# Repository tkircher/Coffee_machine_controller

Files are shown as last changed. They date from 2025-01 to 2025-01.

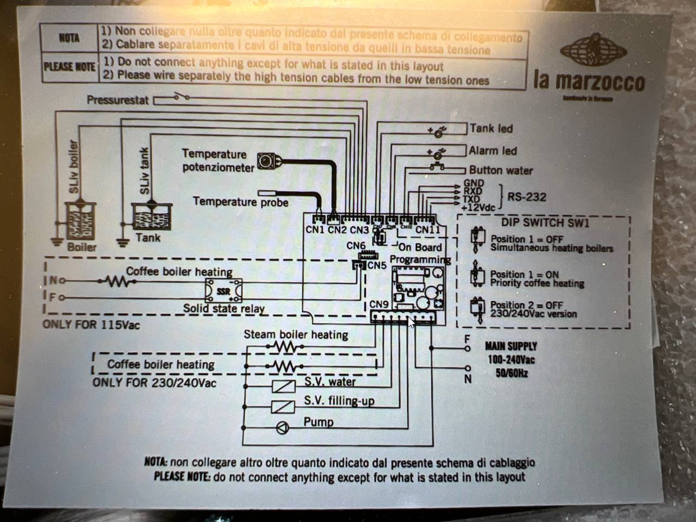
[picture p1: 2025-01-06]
Datasheets/La_Marzocco_control_board_diagram.jpg

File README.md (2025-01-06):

# Coffee_machine_controller
This is a control board for a Linea Mini coffee machine
control_board
control_board_assembled

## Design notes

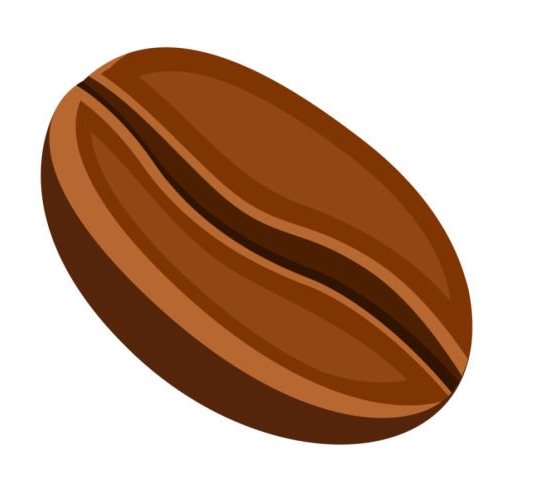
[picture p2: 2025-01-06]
Bean_graphics/coffee_bean_orig.jpg

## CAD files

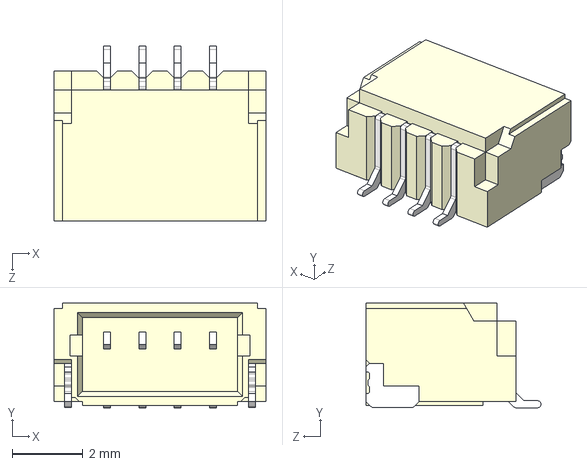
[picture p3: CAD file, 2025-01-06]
3D models/SM04B-SRSS.STEP
6.00 x 2.96 x 4.95 mm

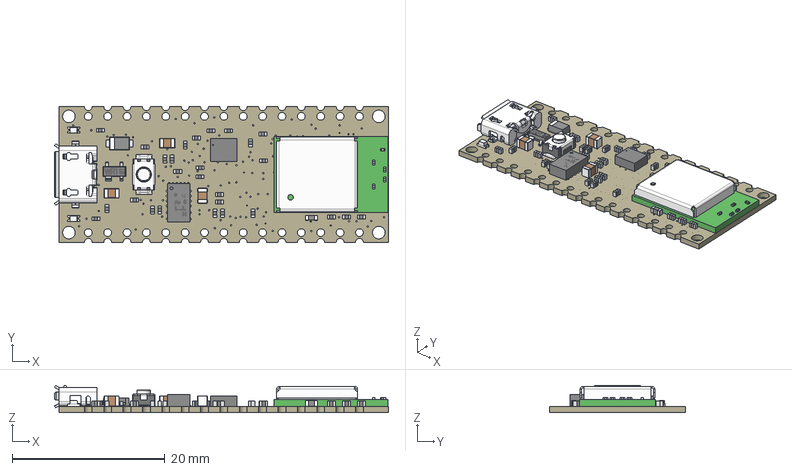
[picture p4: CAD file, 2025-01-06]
3D models/Nano33BLE.step
43.8 x 17.8 x 3.57 mm
Board (1)
LSM9DS1TR_LGA-24_3X3P5X1_STM v1
ZX62-AB-5PA (1)
IoT_HSMG-C190 LED v1 x 2
IoT_MPM3610 Step-Down Module v1
User Library-arduino_nano_reset core
User Library-arduino_nano_reset shell
RC0402FR-071KL RC0402N_YAG v1 x 27
BLM18EG101TN1D v1
C0805C472KDRACTU v1 x 3
PMEG6020AELRX v1
IoT_PRTR5V0U2X Protection Diode v1
NINA-B306-00B-00--3DModel-STEP-56544 v1

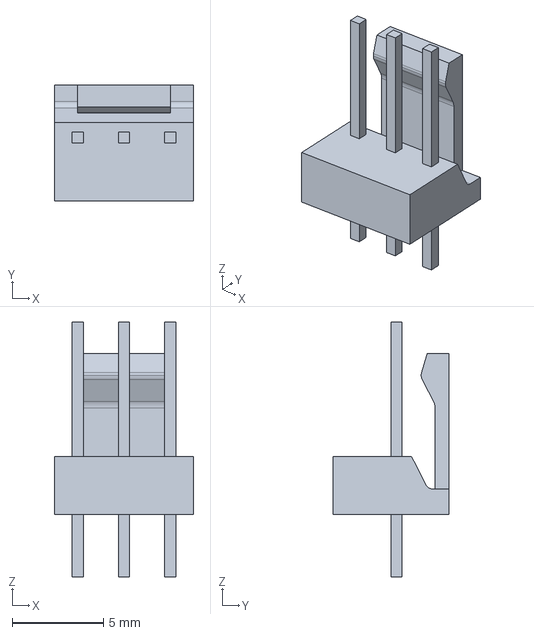
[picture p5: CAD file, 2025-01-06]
3D models/3-647050-3.step
7.62 x 6.35 x 14.0 mm

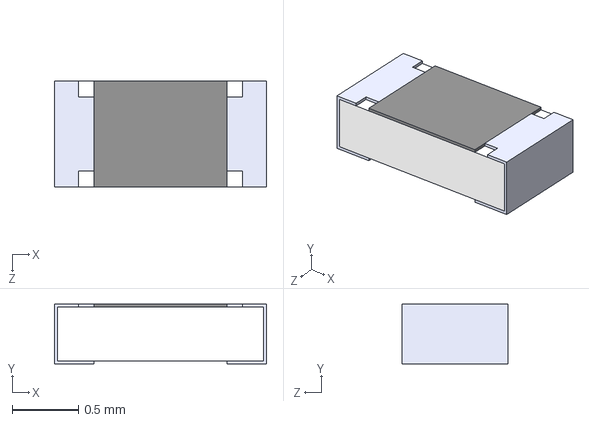
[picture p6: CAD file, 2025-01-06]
3D models/ERJPA3F1003V.step
1.60 x 0.45 x 0.8 mm

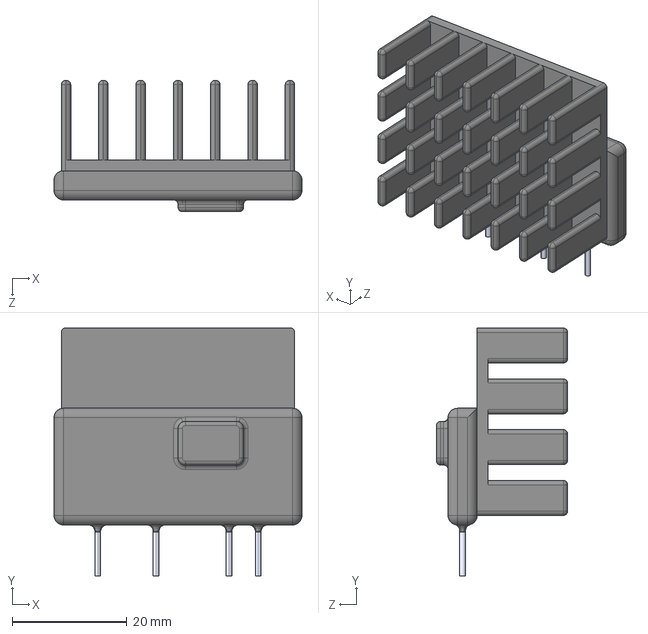
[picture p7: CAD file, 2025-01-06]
3D models/SPF240D25.step
43.2 x 43.2 x 22.9 mm

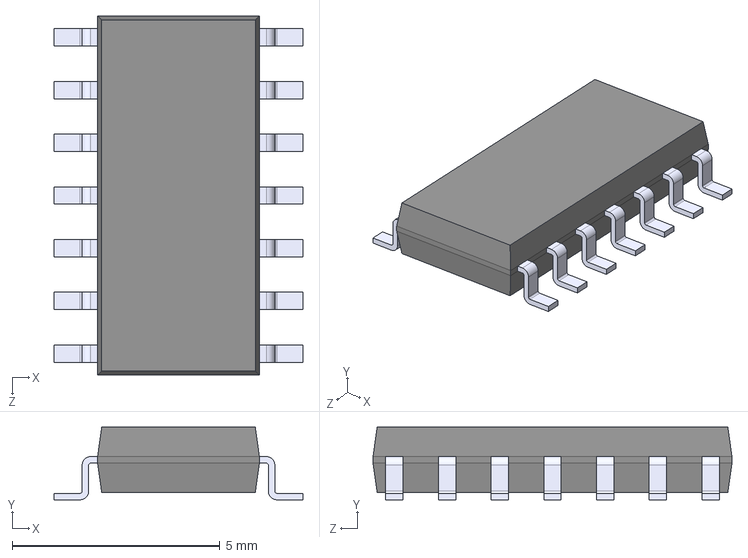
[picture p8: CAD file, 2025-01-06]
3D models/SN74LVC125AD.STEP
6.00 x 1.75 x 8.65 mm

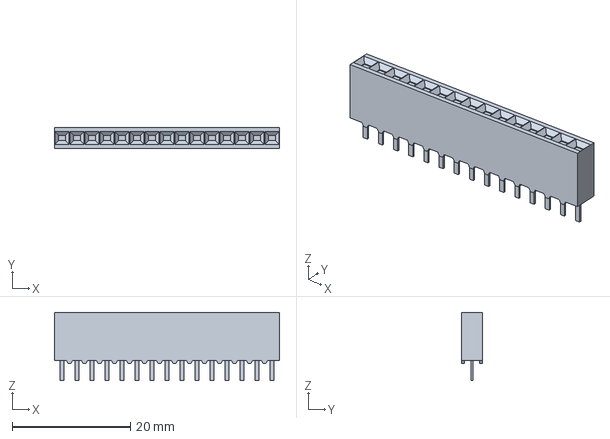
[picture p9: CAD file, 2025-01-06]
3D models/01x15_Arduino_socket.step
38.1 x 3.56 x 11.6 mm

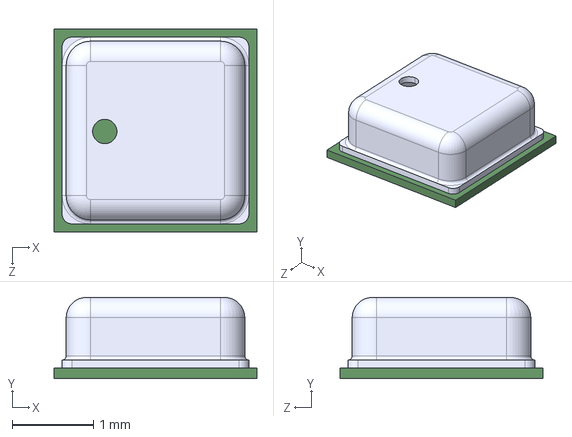
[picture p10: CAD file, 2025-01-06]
3D models/BME280.step
2.50 x 1.00 x 2.50 mm

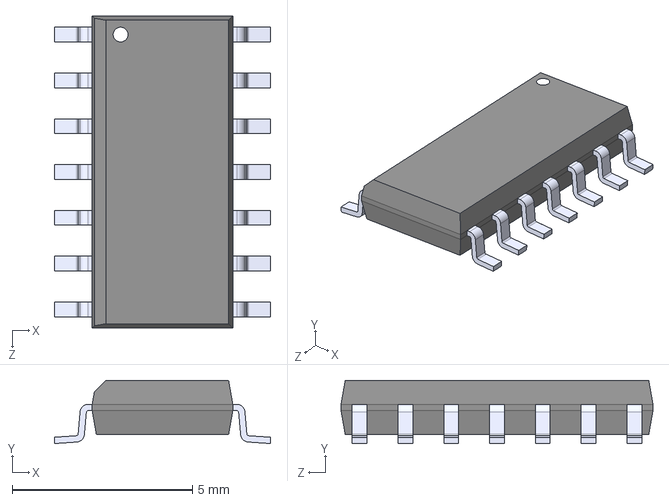
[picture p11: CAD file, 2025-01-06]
3D models/MCP3428-E_SL.step
6.00 x 1.75 x 8.65 mm

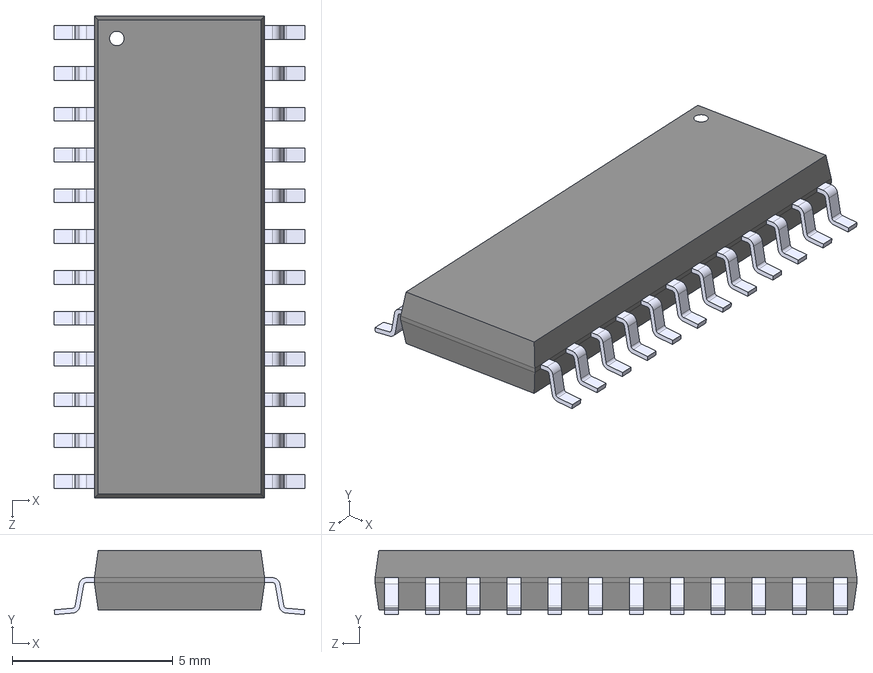
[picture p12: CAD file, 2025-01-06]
3D models/SN74LVC8T245NSR.STEP
7.80 x 2.00 x 15.0 mm

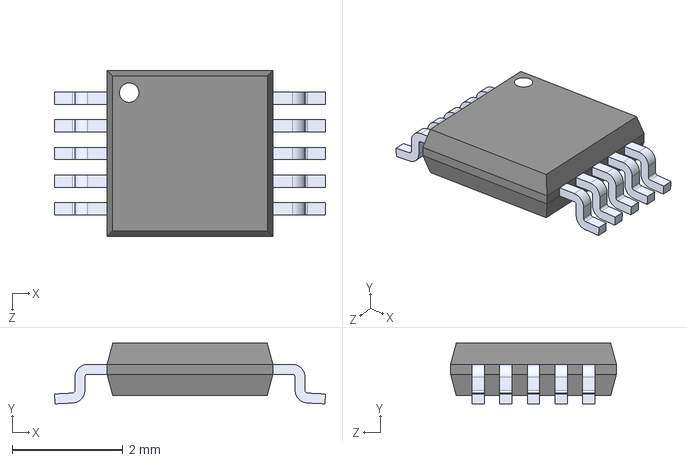
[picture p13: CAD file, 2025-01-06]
3D models/SOP50P490X110-10N.step
4.90 x 1.10 x 3.00 mm

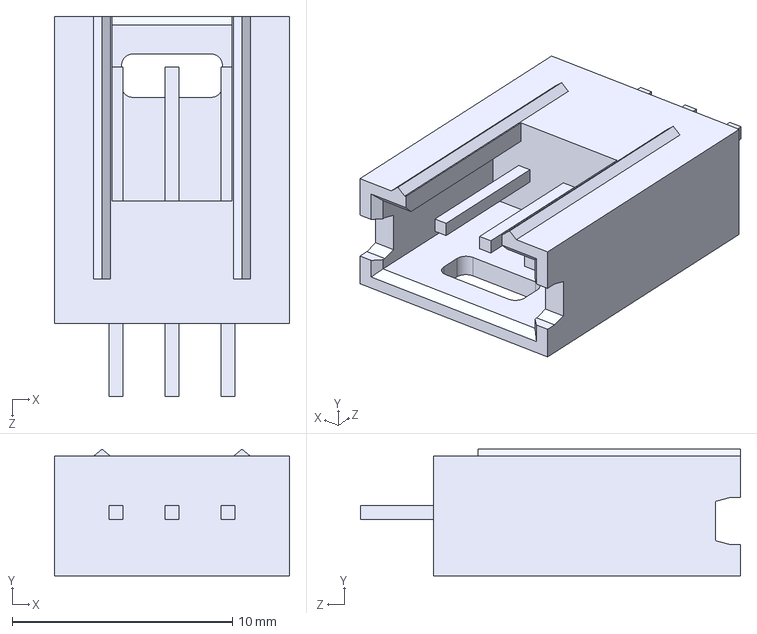
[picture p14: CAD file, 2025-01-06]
3D models/01x03_header.step
10.7 x 5.75 x 17.2 mm

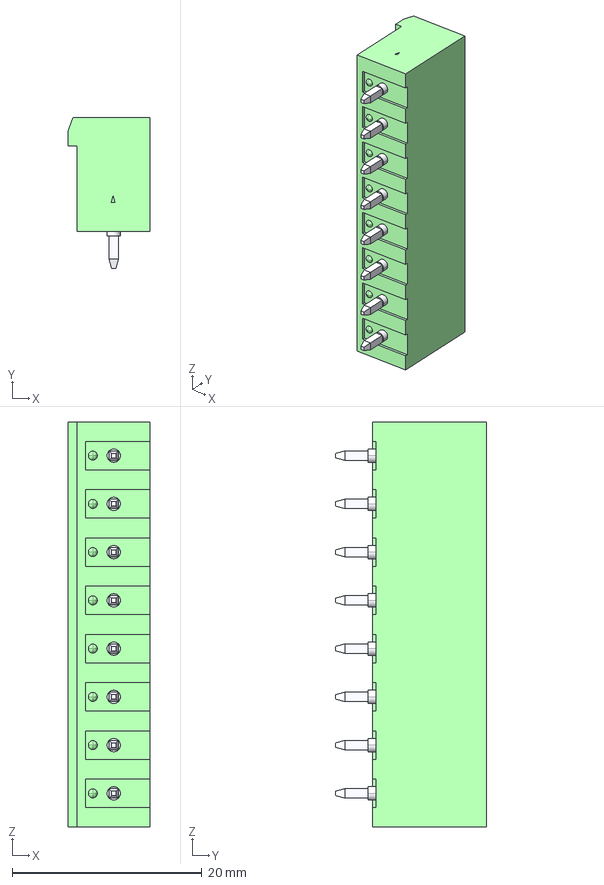
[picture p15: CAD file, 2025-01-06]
3D models/01x08_AC_socket.step
8.60 x 15.9 x 42.6 mm

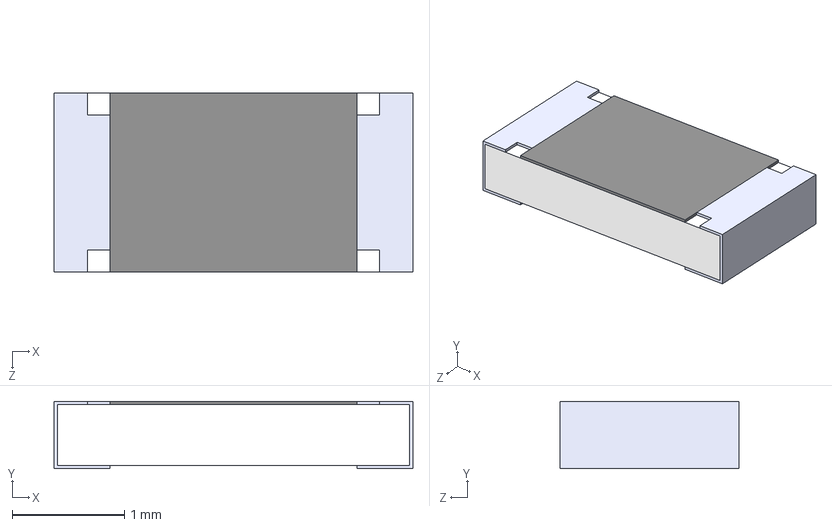
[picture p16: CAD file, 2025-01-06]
3D models/ERA8AEB105V.step
3.20 x 0.6 x 1.60 mm

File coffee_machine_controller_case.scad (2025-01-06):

// Basic case for coffee machine controller board
//
// Thomas Kircher <tkircher@gnu.org>, 2024

// PCB dimensions
board_h = 66;
board_w = 78;

// Mount hole positions
mount_x = 70;
mount_y = 58;

// Cover offsets
cover_h = board_h + 12 - 6;
cover_w = board_w + 12 - 6;
cover_t = 0.6 * 4 + 1.2;

cutout_h = mount_y + 2;
cutout_w = mount_x + 5;

// Middle section offsets
middle_h = board_h - 24;
middle_w = board_w - 20;

// Wall thickness
wall_t = 5 * 0.4;
wall_d1 = 6;
wall_d2 = wall_d1 + 2 * wall_t;

point_d = 3.2 + 2 * 0.4 * 6;

module bottom_outer_ring() {
  outer_d = 10;

  difference() {
    union() {
      // Base
      difference() {
        translate([-cover_w / 2, -cover_h / 2, 0])
          cube([cover_w, cover_h, cover_t]);

        translate([-cutout_w / 2, -cutout_h / 2 - 1 / 2, 1.2])
          cube([cutout_w - 1, cutout_h + 1, cover_t + 1]);
      }

      // Mount points
      for(i = [0 : 1])
      for(j = [0 : 1])
        mirror([i, 0, 0])
        mirror([0, j, 0]) {
        translate([mount_x / 2, mount_y / 2, 0]) {
          cylinder(d = point_d, h = cover_t, $fn = 120);

          translate([-point_d / 2, 0, 0])
            cube([point_d, point_d / 2, cover_t]);

          translate([0, -point_d / 2, 0])
            cube([point_d / 2 + 1, point_d, cover_t]);
        }
      }
    }

    // Mount holes and bottom chamfers
    for(i = [-1 : 2 : 1])
    for(j = [-1 : 2 : 1]) {
      translate([i * mount_x / 2, j * mount_y / 2, -0.1]) {
        cylinder(d = 3.2, h = cover_t + 1, $fn = 120);

        cylinder(d = 5.6, h = 1.2 + 0.1, $fn = 160);

        translate([0, 0, 1.2 + 0.1])
          cylinder(d1 = 5.6, d2 = 3.2, h = 1.8, $fn = 160);
      }
    }

    // Side wall outer fillets
    for(i = [0 : 1])
    for(j = [0 : 1]) {
      mirror([i, 0, 0])
      mirror([0, j, 0])
      translate([-cover_w / 2, -cover_h / 2, -0.1])
      difference() {
        translate([-1, -1, 0])
          cube([outer_d / 2 + 1, outer_d / 2 + 1, cover_t + 1]);

        translate([outer_d / 2, outer_d / 2, -0.1])
          cylinder(d = outer_d, h = cover_t + 2, $fn = outer_d * 24);
      }
    }
  }
}

module bottom_outer_walls(wall_h) {
  difference() {
    union() {
      // Side walls
      for(i = [0 : 1]) {
        mirror([i, 0, 0])
        translate([-cover_w / 2, -cover_h / 2, -wall_h + cover_t])
          cube([wall_t, cover_h, wall_h]);

        mirror([0, i, 0])
        translate([-cover_w / 2, -cover_h / 2, -wall_h + cover_t])
          cube([cover_w, wall_t, wall_h]);
      }

      // Side wall inner fillets
      for(i = [0 : 1])
      for(j = [0 : 1]) {
        mirror([i, 0, 0])
        mirror([0, j, 0]) {
        translate([-cover_w / 2 + wall_t, -cover_h / 2 + wall_t, -wall_h + cover_t])
          difference() {
            cube([wall_d1 / 2, wall_d1 / 2, wall_h]);

            translate([wall_d1 / 2, wall_d1 / 2, -0.1])
              cylinder(d = wall_d1, h = wall_h + 1, $fn = wall_d1 * 24);
          }
        }
      }
    }
    // Side wall outer fillets
    for(i = [0 : 1])
    for(j = [0 : 1]) {
      mirror([i, 0, 0])
      mirror([0, j, 0])
      translate([-cover_w / 2, -cover_h / 2, -0.1 - wall_h + cover_t])
      difference() {
        translate([-1, -1, 0])
          cube([wall_d2 / 2 + 1, wall_d2 / 2 + 1, wall_h + 1]);

        translate([wall_d2 / 2, wall_d2 / 2, -0.1])
          cylinder(d = wall_d2, h = wall_h + 2, $fn = wall_d2 * 24);
      }
    }

    // DC and I2C cutouts
    translate([cover_w / 2 - 45, cover_h / 2 - 10 / 2, cover_t - wall_h])
    difference() {
      cube([23, 10, 10]);

      // Bottom chamfers
      for(i = [0 : 1]) {
        translate([i * (23 + 2.5) - 2.5 / 2, 0, -2.5 / 2])
        rotate([0, 45, 0])
        translate([-5 / 2, 0, -5 / 2])
          cube([5, 5, 5]);
      }
    }

    // Top chamfers
    translate([cover_w / 2 - 45, cover_h / 2 - 10 / 2, cover_t - wall_h])
    for(i = [0 : 1]) {
      translate([i * (23 - 2.5) + 2.5 / 2, 1.5, wall_h + 2.5 / 2])
      rotate([0, 45, 0])
      translate([-5 / 2, 0, -5 / 2])
        cube([5, 5, 5]);
    }
  }
}

module top_outer_ring() {
  //offset = 2 * wall_t + 0.5;
  offset = 0;

  outer_d = 10 + offset;

  cover_h = board_h + 12 - 6 + offset;
  cover_w = board_w + 12 - 6 + offset;

  difference() {
    union() {
      // Base
      difference() {
        translate([-cover_w / 2, -cover_h / 2, 0])
          cube([cover_w, cover_h, cover_t]);

        translate([-cutout_w / 2, -cutout_h / 2 - 1 / 2, 1.2])
          cube([cutout_w - 1, cutout_h + 1, cover_t + 1]);
      }

      // Mount points
      for(i = [0 : 1])
      for(j = [0 : 1])
        mirror([i, 0, 0])
        mirror([0, j, 0]) {
        translate([mount_x / 2, mount_y / 2, 0]) {
          cylinder(d = point_d, h = cover_t, $fn = 120);

          translate([-point_d / 2, 0, 0])
            cube([point_d, point_d / 2, cover_t]);

          translate([0, -point_d / 2, 0])
            cube([point_d / 2 + 1, point_d, cover_t]);
        }
      }
    }

    // Mount holes and bottom chamfers
    for(i = [-1 : 2 : 1])
    for(j = [-1 : 2 : 1]) {
      translate([i * mount_x / 2, j * mount_y / 2, -0.1]) {
        cylinder(d = 3.2, h = cover_t + 1, $fn = 120);

        cylinder(d = 5.6, h = 0.8 + 0.1, $fn = 160);

        translate([0, 0, 0.8 + 0.1])
          cylinder(d1 = 5.6, d2 = 3.2, h = 1.8, $fn = 160);

      }
    }

    // Side wall outer fillets
    for(i = [0 : 1])
    for(j = [0 : 1]) {
      mirror([i, 0, 0])
      mirror([0, j, 0])
      translate([-cover_w / 2, -cover_h / 2, -0.1])
      difference() {
        translate([-1, -1, 0])
          cube([outer_d / 2 + 1, outer_d / 2 + 1, cover_t + 1]);

        translate([outer_d / 2, outer_d / 2, -0.1])
          cylinder(d = outer_d, h = cover_t + 2, $fn = outer_d * 24);
      }
    }
  }
}

module top_inset_walls(wall_h) {
  offset = -4.2;

  wall_d1 = 6 + offset;
  wall_d2 = wall_d1 + 2 * wall_t;

  cover_h = board_h + 12 - 6 + offset;
  cover_w = board_w + 12 - 6 + offset;

  difference() {
    union() {
      // Side walls
      for(i = [0 : 1]) {
        mirror([i, 0, 0])
        translate([-cover_w / 2, -cover_h / 2, -wall_h + cover_t])
          cube([wall_t, cover_h, wall_h]);

        mirror([0, i, 0])
        translate([-cover_w / 2, -cover_h / 2, -wall_h + cover_t])
          cube([cover_w, wall_t, wall_h]);
      }

      // Side wall inner fillets
      for(i = [0 : 1])
      for(j = [0 : 1]) {
        mirror([i, 0, 0])
        mirror([0, j, 0]) {
        translate([-cover_w / 2 + wall_t, -cover_h / 2 + wall_t, -wall_h + cover_t])
          difference() {
            cube([wall_d1 / 2, wall_d1 / 2, wall_h]);

            translate([wall_d1 / 2, wall_d1 / 2, -0.1])
              cylinder(d = wall_d1, h = wall_h + 1, $fn = wall_d1 * 24);
          }
        }
      }
    }

    // Side wall outer fillets
    for(i = [0 : 1])
    for(j = [0 : 1]) {
      mirror([i, 0, 0])
      mirror([0, j, 0])
      translate([-cover_w / 2, -cover_h / 2, -0.1 - wall_h + cover_t])
      difference() {
        translate([-1, -1, 0])
          cube([wall_d2 / 2 + 1, wall_d2 / 2 + 1, wall_h + 1]);

        translate([wall_d2 / 2, wall_d2 / 2, -0.1])
          cylinder(d = wall_d2, h = wall_h + 2, $fn = wall_d2 * 24);
      }
    }
  }
}

module top_outer_walls(wall_h) {
  wall_t = 2.0 + 0.4;
  offset = 0;

  wall_d1 = 6 + offset;
  wall_d2 = wall_d1 + 2 * 2.0;

  cover_h = board_h + 12 - 6 + offset;
  cover_w = board_w + 12 - 6 + offset;

  difference() {
    union() {
      // Side walls
      for(i = [0 : 1]) {
        mirror([i, 0, 0])
        translate([-cover_w / 2, -cover_h / 2, -wall_h + cover_t])
          cube([wall_t, cover_h, wall_h]);

        mirror([0, i, 0])
        translate([-cover_w / 2, -cover_h / 2, -wall_h + cover_t])
          cube([cover_w, wall_t, wall_h]);
      }

      // Side wall inner fillets
      for(i = [0 : 1])
      for(j = [0 : 1]) {
        mirror([i, 0, 0])
        mirror([0, j, 0]) {
        translate([-cover_w / 2 + wall_t, -cover_h / 2 + wall_t, -wall_h + cover_t])
          difference() {
            cube([wall_d1 / 2, wall_d1 / 2, wall_h]);

            translate([wall_d1 / 2, wall_d1 / 2, -0.2])
              cylinder(d = wall_d1, h = wall_h + 0.4, $fn = wall_d1 * 24);
          }
        }
      }

      translate([0, 0, cover_t - wall_h + 19 + 2 - 7])
        top_inset_walls(19 + 2);
    }

    // Side wall outer fillets
    for(i = [0 : 1])
    for(j = [0 : 1]) {
      mirror([i, 0, 0])
      mirror([0, j, 0])
      translate([-cover_w / 2, -cover_h / 2, -0.1 - wall_h + cover_t])
      difference() {
        translate([-1, -1, 0])
          cube([wall_d2 / 2 + 1, wall_d2 / 2 + 1, wall_h + 1]);

        translate([wall_d2 / 2, wall_d2 / 2, -0.1])
          cylinder(d = wall_d2, h = wall_h + 2, $fn = wall_d2 * 24);
      }
    }
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

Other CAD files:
3D models/01x06_header.step
3D models/01x04_header.step
3D models/aq1208.step
3D models/RAC05-05SK.step
3D models/01x02_socket.step
3D models/103906-6.step
3D models/AQG22105.step
3D models/MCP23008-E_SO.STEP

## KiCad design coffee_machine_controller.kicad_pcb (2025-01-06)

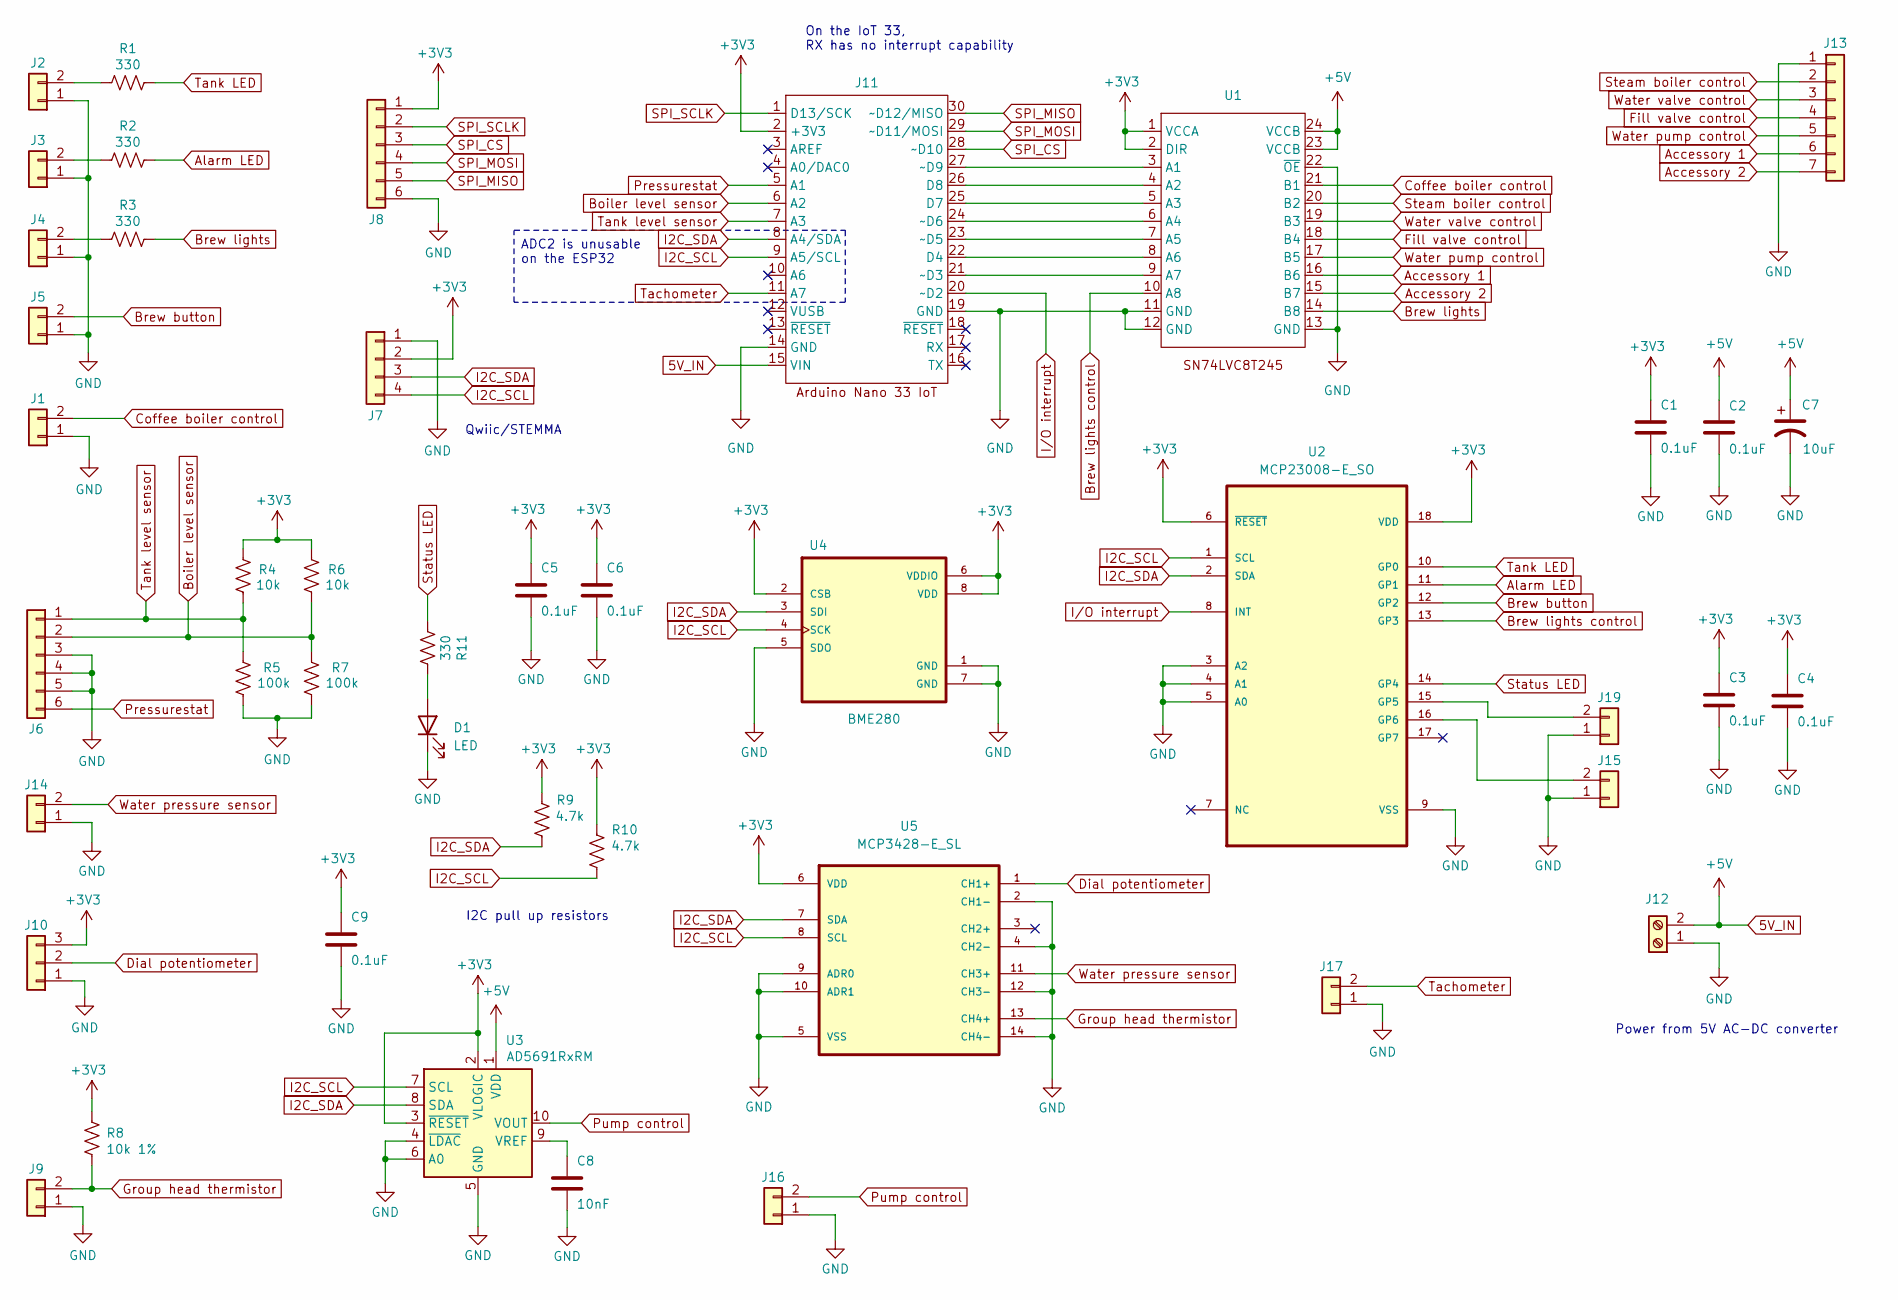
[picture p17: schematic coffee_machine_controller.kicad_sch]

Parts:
C1, C2, C3, C4, C5, C6, C9: 0.1uF; C_0805_2012Metric
C7: 10uF; CP_EIA-3216-18_Kemet-A
C8: 10nF; C_0805_2012Metric
D1: LED; LED_0805_2012Metric
J1, J2, J3, J4, J5, J9, J14, J15, J16, J17, J19: Conn_01x02; PinHeader_1x02_P2.54mm_Vertical
J6: Conn_01x06; PinHeader_1x06_P2.54mm_Vertical
J7: Conn_01x04; JST_SH_SM04B-SRSS-TB_1x04-1MP_P1.00mm_Horizontal
J8: Conn_01x06; PinHeader_1x06_P2.54mm_Vertical_DNP
J10: Conn_01x03; PinHeader_1x03_P2.54mm_Vertical
J11: Arduino_Nano_33_IoT_SMD
J12: Screw_Terminal_01x02; Terminal_block_01x02
J13: Conn_01x07; PinSocket_1x07_P2.54mm_Vertical
R1, R2, R3, R11: 330; R_0805_2012Metric
R4, R6: 10k; R_0805_2012Metric
R5, R7: 100k; R_0805_2012Metric
R8: 10k 1%; R_0805_2012Metric
R9, R10: 4.7k; R_0805_2012Metric
U1: SOP127P780X200-24N
U2: MCP23008-E_SO; SOIC127P1030X265-18N
U3: AD5691RxRM; MSOP-10_3x3mm_P0.5mm
U4: BME280; PSON65P250X250X100-8N
U5: MCP3428-E_SL; SOIC127P600X175-14N

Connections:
5V_IN: C2.1, C7.1, J11.15 (VIN), J12.2, U1.23 (VCCB), U1.24 (VCCB), U3.1 (VDD)
+3V3: C1.1, C3.1, C4.1, C5.1, C6.1, C9.1, J7.2, J8.1, J10.3, J11.2 (+3V3), R4.2, R6.2, R8.2, R9.2, R10.2, U1.1 (VCCA), U1.2 (DIR), U2.6 (~RESET), U2.18 (VDD), U3.2 (VLOGIC), U3.3 (~RESET), U4.2 (CSB), U4.6 (VDDIO), U4.8 (VDD), U5.6 (VDD)
Accessory 1: J13.6, U1.16 (B6)
Accessory 2: J13.7, U1.15 (B7)
Alarm LED: R2.2, U2.11 (GP1)
Boiler level sensor: J6.2, J11.6 (A2), R6.1, R7.2
Brew button: J5.2, U2.12 (GP2)
Brew lights: R3.2, U1.14 (B8)
Brew lights control: U1.10 (A8), U2.13 (GP3)
Coffee boiler control: J1.2, U1.21 (B1)
Dial potentiometer: J10.2, U5.1 (CH1+)
Fill valve control: J13.4, U1.18 (B4)
GND: C1.2, C2.2, C3.2, C4.2, C5.2, C6.2, C7.2, C8.2, C9.2, D1.1 (K), J1.1, J2.1, J3.1, J4.1, J5.1, J6.3, J6.4, J6.5, J7.1, J8.6, J9.1, J10.1, J11.14 (GND), J11.19 (GND), J12.1, J13.1, J14.1, J15.1, J16.1, J17.1, J19.1, R5.1, R7.1, U1.11 (GND), U1.12 (GND), U1.13 (GND), U1.22 (~OE), U2.3 (A2), U2.4 (A1), U2.5 (A0), U2.9 (VSS), U3.4 (~LDAC), U3.5 (GND), U3.6 (A0), U4.1 (GND), U4.5 (SDO), U4.7 (GND), U5.2 (CH1-), U5.4 (CH2-), U5.5 (VSS), U5.9 (ADR0), U5.10 (ADR1), U5.12 (CH3-), U5.14 (CH4-)
Group head thermistor: J9.2, R8.1, U5.13 (CH4+)
I2C_SCL: J7.4, J11.9 (A5/SCL), R10.1, U2.1 (SCL), U3.7 (SCL), U4.4 (SCK), U5.8 (SCL)
I2C_SDA: J7.3, J11.8 (A4/SDA), R9.1, U2.2 (SDA), U3.8 (SDA), U4.3 (SDI), U5.7 (SDA)
I/O interrupt: J11.20 (~D2), U2.8 (INT)
unnamed: D1.2 (A), R11.2
unnamed: J2.2, R1.1
unnamed: J3.2, R2.1
unnamed: J4.2, R3.1
unnamed: J11.22 (D4), U1.8 (A6)
unnamed: J11.25 (D7), U1.5 (A3)
unnamed: J11.26 (D8), U1.4 (A2)
unnamed: J11.21 (~D3), U1.9 (A7)
unnamed: J11.23 (~D5), U1.7 (A5)
unnamed: J11.24 (~D6), U1.6 (A4)
unnamed: J11.27 (~D9), U1.3 (A1)
unnamed: J15.2, U2.16 (GP6)
unnamed: J19.2, U2.15 (GP5)
unnamed: C8.1, U3.9 (VREF)
Pressurestat: J6.6, J11.5 (A1)
Pump control: J16.2, U3.10 (VOUT)
SPI_CS: J8.3, J11.28 (~D10)
SPI_MISO: J8.5, J11.30 (~D12/MISO)
SPI_MOSI: J8.4, J11.29 (~D11/MOSI)
SPI_SCLK: J8.2, J11.1 (D13/SCK)
Status LED: R11.1, U2.14 (GP4)
Steam boiler control: J13.2, U1.20 (B2)
Tachometer: J11.11 (A7), J17.2
Tank LED: R1.2, U2.10 (GP0)
Tank level sensor: J6.1, J11.7 (A3), R4.1, R5.2
Water pressure sensor: J14.2, U5.11 (CH3+)
Water pump control: J13.5, U1.17 (B5)
Water valve control: J13.3, U1.19 (B3)

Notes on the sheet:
Qwiic/STEMMA
I2C pull up resistors
On the IoT 33, RX has no interrupt capability
Power from 5V AC-DC converter
ADC2 is unusable on the ESP32

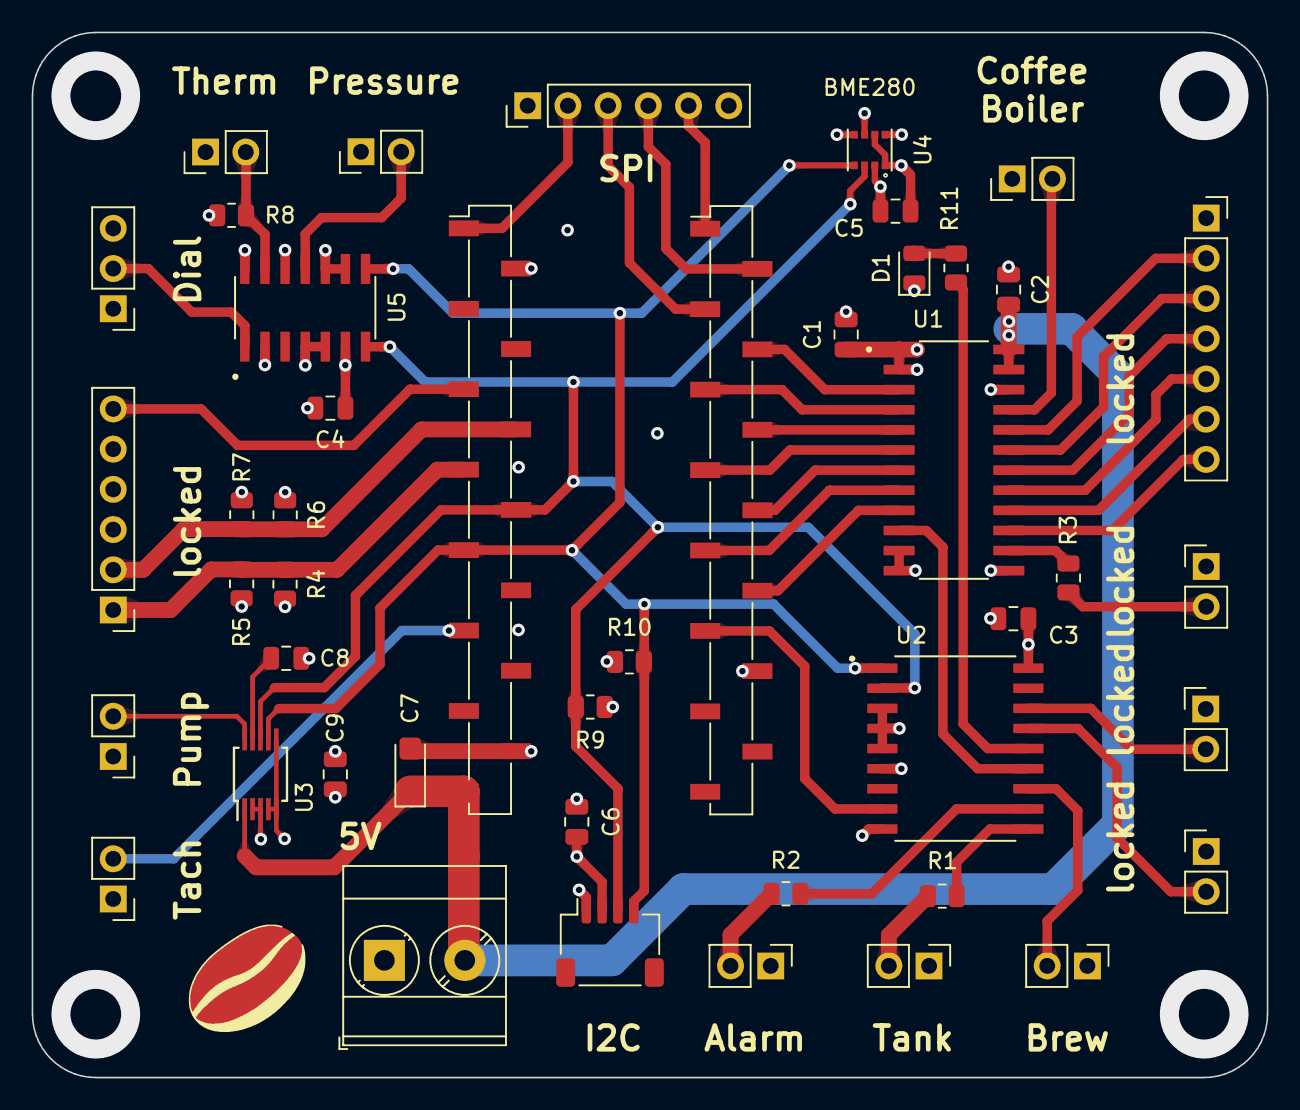
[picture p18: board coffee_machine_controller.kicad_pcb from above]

Board: 4 copper layers, 78.0 x 66.0 mm, 44 parts (0 on the bottom side), 45 nets.

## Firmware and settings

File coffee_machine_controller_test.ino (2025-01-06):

#include <Wire.h>
#include <Adafruit_MCP23X08.h>
#include <Adafruit_BME280.h>
#include <Adafruit_AD569x.h>
#include <MCP342x.h>

// Whether we're building for ESP32 or not
#undef ESP32

// Pin    Arduino pin     ESP32 GPIO     Function
// ---    -----------     ----------     --------
// D0      0              44             -
// D1      1              43             -
// D2      2               5             I/O interrupt
// D3      3               6             Accessory 2
// D4      4               7             Accessory 1
// D5      5               8             Water pump control
// D6      6               9             Fill valve control
// D7      7              10             Water valve control
// D8      8              17             Steam boiler control
// D9      9              18             Coffee boiler control
// D10    10              21             SPI_CS
// D11    11              38             SPI_MOSI
// D12    12              47             SPI_MISO
// D13    13              48             SPI_SCLK
// LED_R  14              46             -
// LED_G  15               0             -
// LED_B  16              45             -
// A0     17               1             -
// A1     18               2             Pressurestat
// A2     19               3             Boiler level sensor
// A3     20               4             Tank level sensor
// A4     21              11             I2C_SDA
// A5     22              12             I2C_SCL
// A6     23              13             -
// A7     24              14             Gear pump tachometer


#ifdef ESP32 // We are using GPIO numbering

#define IO_INTERRUPT            5
#define WATER_PUMP              8
#define ACCESSORY_1             7
#define ACCESSORY_2             6
#define WATER_VALVE             10
#define FILL_VALVE              9
#define STEAM_BOILER            17
#define COFFEE_BOILER           18

#define LED_R                   46
#define LED_G                   0
#define LED_B                   45

#define PRESSURESTAT            2
#define BOILER_AUTOFILL_PROBE   3
#define RESERVOIR_LEVEL_PROBE   4
#define TACHOMETER              14

#else // Arduino IoT 33

#define IO_INTERRUPT            2
#define WATER_PUMP              5
#define ACCESSORY_1             4
#define ACCESSORY_2             3
#define WATER_VALVE             7
#define FILL_VALVE              6
#define STEAM_BOILER            8
#define COFFEE_BOILER           9

#define PRESSURESTAT            A1
#define BOILER_AUTOFILL_PROBE   A2
#define RESERVOIR_LEVEL_PROBE   A3
#define TACHOMETER              A7

#endif // ESP32 or IoT 33

// These are the port numbers for the I/O expander
#define TANK_LED                0
#define ALARM_LED               1
#define BREW_BUTTON             2
#define BREW_LIGHTS             3
#define STATUS_LED              4
#define IO_1                    5
#define IO_2                    6
// GP7 not used

// These are the channel numbers for the ADC
#define DIAL_POTENTIOMETER      1
// Channel 2 is shorted to ground
#define PRESSURE_SENSOR         3
#define THERMISTOR              4

Adafruit_MCP23X08 mcp;
Adafruit_BME280 bme;
Adafruit_AD569x ad5693; // 12-bit DAC
MCP342x adc = MCP342x(0x68); // MCP3424 address is 0x6e

int i;
int timeout = 1000000; // 1 second timeout

float boiler_probe;
float reservoir_probe;
int pressurestat;
float potentiometer;
float pressure;
float thermistor;
float bme_temperature;
float bme_pressure;
float bme_humidity;

int DAC_value = 0;
bool button_flag = false;

#ifdef ESP32

void IRAM_ATTR isr() {
  button_flag = true;
}

const uint8_t HSVlights[61] = 
{0, 4, 8, 13, 17, 21, 25, 30, 34, 38, 42, 47, 51, 55, 59, 64, 68, 72, 76,
81, 85, 89, 93, 98, 102, 106, 110, 115, 119, 123, 127, 132, 136, 140, 144,
149, 153, 157, 161, 166, 170, 174, 178, 183, 187, 191, 195, 200, 204, 208,
212, 217, 221, 225, 229, 234, 238, 242, 246, 251, 255};

// the real HSV rainbow
void trueHSV(int angle)
{
  byte red, green, blue;

  if (angle<60) {red = 255; green = HSVlights[angle]; blue = 0;} else
  if (angle<120) {red = HSVlights[120-angle]; green = 255; blue = 0;} else 
  if (angle<180) {red = 0, green = 255; blue = HSVlights[angle-120];} else 
  if (angle<240) {red = 0, green = HSVlights[240-angle]; blue = 255;} else 
  if (angle<300) {red = HSVlights[angle-240], green = 0; blue = 255;} else 
                 {red = 255, green = 0; blue = HSVlights[360-angle];} 

  analogWrite(LED_R, red);
  analogWrite(LED_G, green);
  analogWrite(LED_B, blue);
}

#else

void isr() {
    button_flag = true;
}

void trueHSV(int angle) {
  return;
}

#endif // RGB LED only exists on the ESP32, interrupts are different

void setup() {  
  // Set up Arduino I/O
  pinMode(WATER_PUMP, OUTPUT);
  pinMode(ACCESSORY_1, OUTPUT);
  pinMode(ACCESSORY_2, OUTPUT);
  pinMode(WATER_VALVE, OUTPUT);
  pinMode(FILL_VALVE, OUTPUT);
  pinMode(STEAM_BOILER, OUTPUT);
  pinMode(COFFEE_BOILER, OUTPUT);

  pinMode(IO_INTERRUPT, INPUT_PULLUP);
  pinMode(PRESSURESTAT, INPUT_PULLUP);
  pinMode(BOILER_AUTOFILL_PROBE, INPUT);
  pinMode(RESERVOIR_LEVEL_PROBE, INPUT);
  pinMode(TACHOMETER, INPUT_PULLUP);

#ifdef ESP32
  pinMode(LED_R, OUTPUT);
  pinMode(LED_G, OUTPUT);
  pinMode(LED_B, OUTPUT);
#endif

  // These are all off by default 
  digitalWrite(WATER_PUMP, LOW);
  digitalWrite(ACCESSORY_1, LOW);
  digitalWrite(ACCESSORY_2, LOW);
  digitalWrite(WATER_VALVE, LOW);
  digitalWrite(FILL_VALVE, LOW);
  digitalWrite(STEAM_BOILER, LOW);
  digitalWrite(COFFEE_BOILER, LOW);

#ifdef ESP32
  // Start with RGB all on
  analogWrite(LED_R, 64);
  analogWrite(LED_G, 64);
  analogWrite(LED_B, 64);
#endif

  // Start the serial interface
  Serial.begin(115200);

  // Start up the MCP23008
  mcp.begin_I2C();

  // Set up interrupts
  mcp.setupInterrupts(true, false, LOW);

  // The brew button is the only input
  for(i = 0; i < 8; i++) {
    if(i == BREW_BUTTON) {
      mcp.pinMode(i, INPUT_PULLUP);
      mcp.setupInterruptPin(i, LOW);
    }
    else {
      mcp.pinMode(i, OUTPUT);

      // Turn on the brew lights
      if((i == BREW_LIGHTS) || (i == STATUS_LED) || (i == IO_1))
        mcp.digitalWrite(i, HIGH);
      else
        mcp.digitalWrite(i, LOW);
    }
  }

  // Start up the DAC, set voltage to zero
  ad5693.begin(0x4C, &Wire);
  delay(100);
  ad5693.reset();
  ad5693.setMode(NORMAL_MODE, true, true);
  ad5693.writeUpdateDAC(0);

  // BME280, SDO is wired to ground so I2C address is 0x76
  bme.begin(0x76, &Wire);

  // Initialize ADC
  MCP342x::generalCallReset();

  // Wait for everything to catch up
  delay(1000);

  // Make sure the ADC is really there
  Wire.requestFrom(0x68, (uint8_t)1);
  if(!Wire.available()) {
    delay(1000);
    Serial.println("ADC not found");
    while(1);
  }

	attachInterrupt(IO_INTERRUPT, isr, CHANGE);
}

void read_sequence() {
  long value; // ADC reading
  MCP342x::Config status; // ADC status

  for(int i = 0; i < 11; i++) {
    // Handle interrupt
    if(button_flag == true) {
      button_flag = false;
      if(mcp.digitalRead(BREW_BUTTON) == HIGH)
        mcp.digitalWrite(STATUS_LED, HIGH);
      else
        mcp.digitalWrite(STATUS_LED, LOW);
    }

    switch(i) {
      case 0: // Read boiler probe (output in volts)
        boiler_probe = ((float)analogRead(BOILER_AUTOFILL_PROBE) * 3.3) / 1024.0;
        break;
      case 1: // Read reservoir probe (output in volts)
        reservoir_probe = ((float)analogRead(RESERVOIR_LEVEL_PROBE) * 3.3) / 1024.0;
        break;
      case 2: // Read pressurestat
        pressurestat = digitalRead(PRESSURESTAT);
        break;
      case 3: // Read analog dial
        adc.convertAndRead(MCP342x::channel1, MCP342x::oneShot, MCP342x::resolution16, MCP342x::gain1, timeout, value, status);
        potentiometer = value;
        break;
      case 4: // Read pressure sensor
        adc.convertAndRead(MCP342x::channel3, MCP342x::oneShot, MCP342x::resolution16, MCP342x::gain1, timeout, value, status);
        pressure = value;
        break;
      case 5: // Read brew head thermistor
        adc.convertAndRead(MCP342x::channel4, MCP342x::oneShot, MCP342x::resolution16, MCP342x::gain1, timeout, value, status);
        thermistor = value;
        break;
      case 6: // Read BME280 sensor value
        bme_temperature = bme.readTemperature();
        break;
      case 7: // Read BME280 pressure
        bme_pressure = bme.readPressure() / 100.0F;
        break;
      case 8: // Read BME280 humidity
        bme_humidity = bme.readHumidity();
      case 9: // Update DAC
        ad5693.writeUpdateDAC(DAC_value);
        if(DAC_value > 65400) DAC_value = 0; else DAC_value += 1023;
        break;
      default:
        Serial.print("Boiler level: "); Serial.println(boiler_probe);
        Serial.print("Tank level: "); Serial.println(reservoir_probe);
        Serial.print("Pressurestat: "); Serial.println(pressurestat);
        Serial.print("Dial: "); Serial.println(potentiometer);
        Serial.print("Line pressure: "); Serial.println(pressure);
        Serial.print("Group temp: "); Serial.println(thermistor);
        Serial.print("Case temp: "); Serial.println(bme_temperature);
        Serial.print("Air pressure: "); Serial.println(bme_pressure);
        Serial.print("Humidity: "); Serial.println(bme_humidity);
        Serial.println();
        break;
    }
  }
}

void loop() {
  for(int n = 0; n < 360; n += 2) {
    read_sequence();
    trueHSV(n);
  }
}

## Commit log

2025-01-06 Added a KiCAD board render
2025-01-06 Added photo of real board
